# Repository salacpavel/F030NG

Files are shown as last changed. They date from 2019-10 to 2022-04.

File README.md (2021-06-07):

# F030NG
A ground-up remake of famous Atari Falcon 030 hardware, using contemporary components and technologies wherever possible, while maintaining maximum compatibility with original Atari system.
It aims to fix outstanding stability issues of original Falcon and introduces number of changes and exciting new features, such as
- **New (proprietary) thin desktop form factor**, closer to never released Atari Microbox030
- ~~Incorporates much, **much faster DSP with four times more on-board memory**~~ Due to identified incompatibilities of MC56303 DSP, on-board implementation of the DSP processor has been omitted in favour of expansion slot with all DSP signals on it. This enables development and use of DSP based plug-in boards in different configurations and forms, such as advanced digital sound cards, data processors, oscilloscopes, etc. Basic form of plug/in board will have MC56001 on it.
- Replaces fixed TOS/ROM socket with swappable add-on modules, what gives room for flash memory based TOS switchers etc.
- IDE port is relocated to allow simple use of cheap and ubiquitous CF-IDE adaptors, with CF conveniently accessible from the outside of the computer. Internal PATA laptop HDD is still an option
- External SCSI replaced with standard **internal 50 pin SCSI interface**. External port can be added with simple breakout board
- Removes two STE jagpad ports to save some space and simplify motherboard design
- ~~Expands internal expansion connector for additional pins to allow more different devices to be build, such as test and diagnostics cart (TBD), while still maintaining full compatibility with CT60(e) accelerator~~ no longer necessary, see below
- ~~Removes legacy cartridge interface due to general unavailability of replacement edge board connectors~~ Unobtainable legacy cartridge port edge card connector has been replaced with compatible replacement PCB/connector assebmbly
- **Redesigned TV-out circuit** is now based on more recent AD725 chip, providing higher quality output. S-Video output is now supported as well.
- Completely remade board power distribution to avoid need for most of leaky electrolytic capacitors. The rest of them is radial now, due to space and obsolescence concerns.
- **HiFi audio** components used for audio-in and audio-out
- Failing NVRAM chip replaced with more recent DS12885 backed by common replaceable CR1220 coin cell
- External and internal keyboard connectors
- Proprietary Atari 19-pin video connector replaced with common **VGA interface**. Now you can plug your VGA monitor directly, without a need for a convertor.
- Onboard implementation of NetUSB adds **one 10-mbit LAN port and two USB ports** (with number of USB devices currently supported)
- **Fully redesigned base clock system**. Whole universe of overclocking options is now available out of the box.  In example you can double the system clock while keeping CPU base clock, bump the CPU base clock in 8 steps, clock FPU independently, etc. Hard to obtain 32.098488MHz base clock crystal in no longer needed, unless you require 100% compatibility with clock-dependant graphics demos.
- Smaller motherboard footprint, with only 325.6x225mm outer dimensions
- Four-layer design compared to original six-layer Falcon mainboard for a lower production cost (around 20USD/pc) and easier manufacturing
- Optimized track routing to avoid infamous Falcon stability issue and need for different clock patches.
- Many more smaller fixes and changes, too many to name them all.

The F030 will eventually be available as bare/half-way/fully assembled mainboards and add-on cards through centuriontech.eu web shop, or available as a set of instruction, how-to and manufacturing data for DIY enthusiasts.

## Discussion platform:
Now you can discuss about F030NG on Discord: https://discord.gg/jRaXBVc

## Documentation:
Want to get started yourself? Read the [GitHub Wiki](https://github.com/salacpavel/F030NG/wiki)

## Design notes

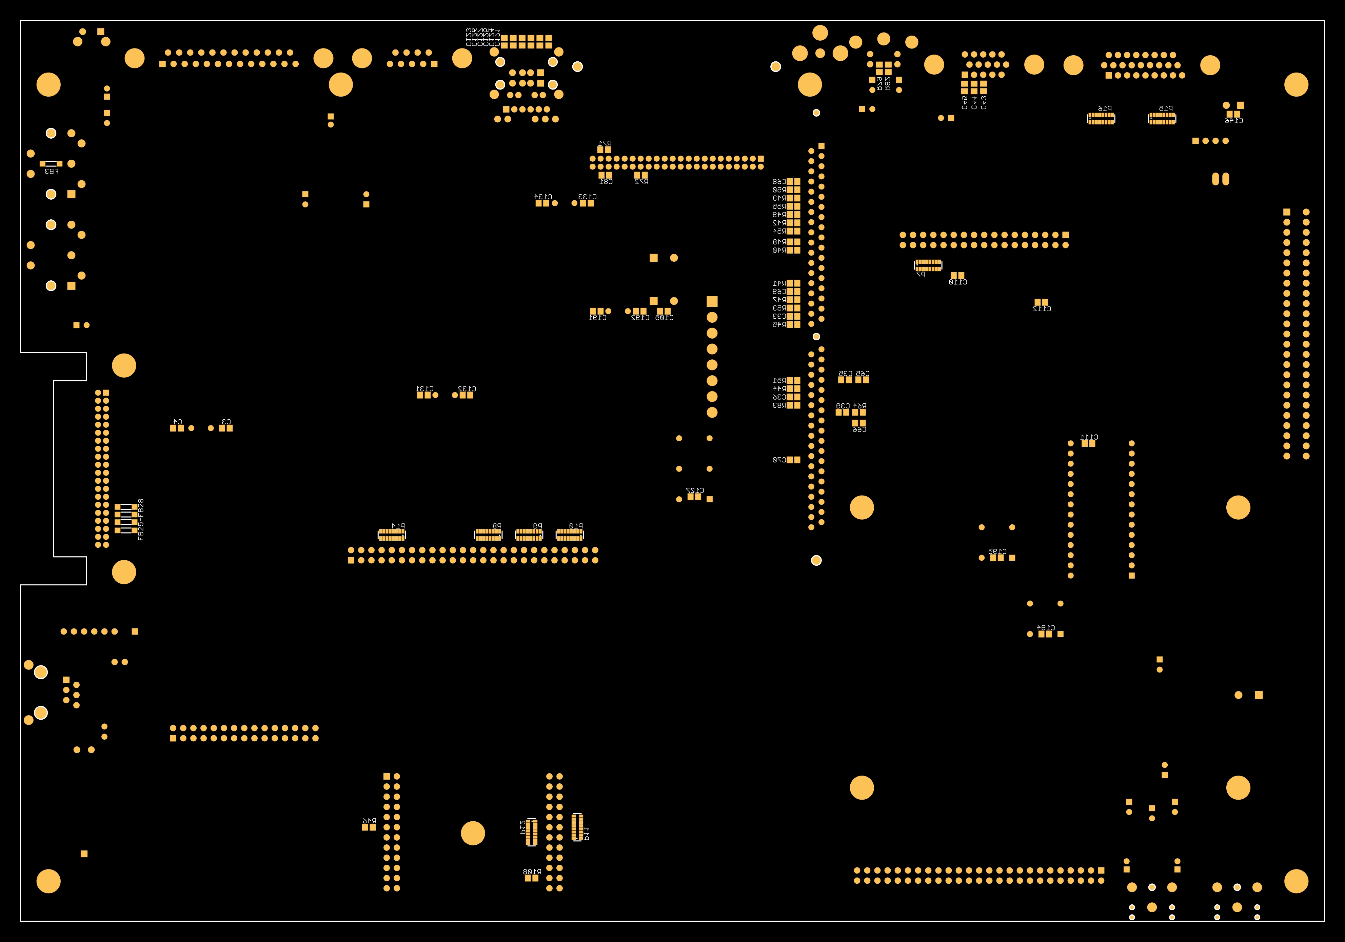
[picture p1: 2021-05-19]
F030NG_R02b bot.jpg

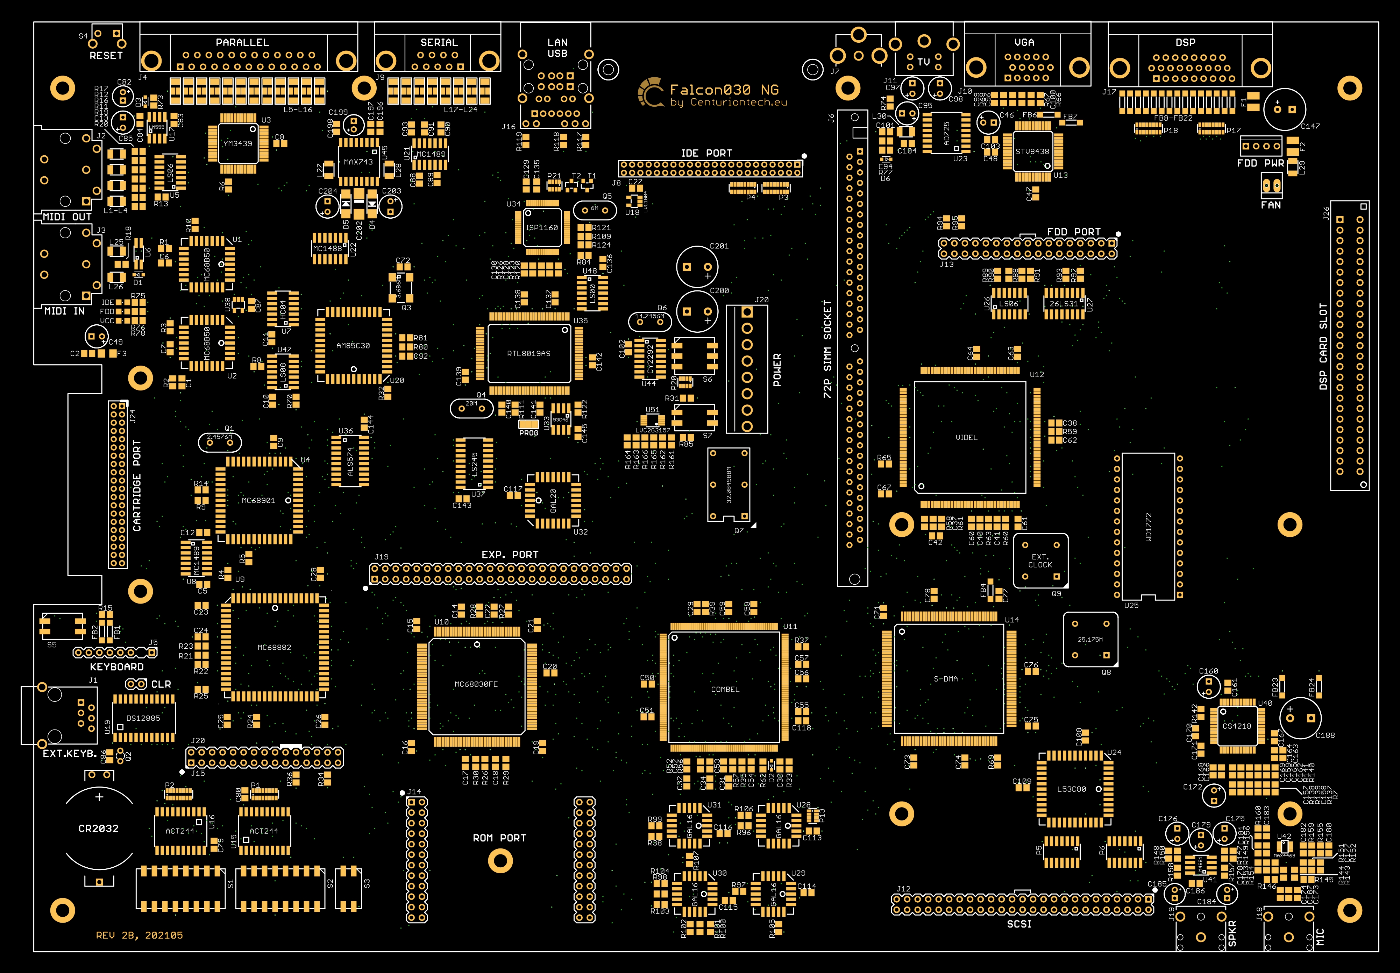
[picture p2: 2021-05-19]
F030NG_R02b top.JPG

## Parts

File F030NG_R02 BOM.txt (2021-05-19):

Part     Value                  Device                         Package          Library        Sheet

BAT1     CR2032                 CR2032-T                       CH29-2032        F030NG         8
C1       68p                    C-EUC0805                      C0805            rcl            1
C2       1u                     C-EUC0805                      C0805            rcl            15
C3       33p                    C-EUC0805                      C0805            rcl            1
C4       33p                    C-EUC0805                      C0805            rcl            1
C5       100p                   C-EUC0805                      C0805            rcl            1
C6       100n                   C-EUC0805                      C0805            rcl            1
C7       100n                   C-EUC0805                      C0805            rcl            1
C8       100n                   C-EUC0805                      C0805            rcl            1
C9       100n                   C-EUC0805                      C0805            rcl            1
C10      100n                   C-EUC0805                      C0805            rcl            1
C11      100n                   C-EUC0805                      C0805            rcl            1
C12      100n                   C-EUC0805                      C0805            rcl            1
C13      100n                   C-EUC0805                      C0805            rcl            1
C14      100n                   C-EUC0805                      C0805            rcl            2
C15      100n                   C-EUC0805                      C0805            rcl            2
C16      100n                   C-EUC0805                      C0805            rcl            2
C17      100n                   C-EUC0805                      C0805            rcl            2
C18      100n                   C-EUC0805                      C0805            rcl            2
C19      100n                   C-EUC0805                      C0805            rcl            2
C20      100n                   C-EUC0805                      C0805            rcl            2
C21      100n                   C-EUC0805                      C0805            rcl            2
C22      100n                   C-EUC0805                      C0805            rcl            2
C23      100n                   C-EUC0805                      C0805            rcl            2
C24      100n                   C-EUC0805                      C0805            rcl            2
C25      100n                   C-EUC0805                      C0805            rcl            2
C26      100n                   C-EUC0805                      C0805            rcl            2
C27      100n                   C-EUC0805                      C0805            rcl            8
C28      1u                     C-EUC0805                      C0805            rcl            2
C29      10p                    C-EUC0805                      C0805            rcl            3
C30      1u                     C-EUC0805                      C0805            rcl            3
C31      10p                    C-EUC0805                      C0805            rcl            3
C32      10p                    C-EUC0805                      C0805            rcl            3
C33      10p                    C-EUC0805                      C0805            rcl            3
C34      10p                    C-EUC0805                      C0805            rcl            3
C35      10p                    C-EUC0805                      C0805            rcl            3
C36      10p                    C-EUC0805                      C0805            rcl            3
C37      68p                    C-EUC0805                      C0805            rcl            3
C38      68p                    C-EUC0805                      C0805            rcl            3
C39      68p                    C-EUC0805                      C0805            rcl            3
C40      68p                    C-EUC0805                      C0805            rcl            3
C41      68p                    C-EUC0805                      C0805            rcl            3
C42      68p                    C-EUC0805                      C0805            rcl            3
C43      47p                    C-EUC0805                      C0805            rcl            3
C44      47p                    C-EUC0805                      C0805            rcl            3
C45      47p                    C-EUC0805                      C0805            rcl            3
C46      100u                   CPOL-EUE2.5-6                  E2,5-6           rcl            10
C47      100n                   C-EUC0805                      C0805            rcl            3
C48      100n                   C-EUC0805                      C0805            rcl            3
C49      100u                   CPOL-EUE2.5-6                  E2,5-6           rcl            15
C50      100n                   C-EUC0805                      C0805            rcl            3
C51      100n                   C-EUC0805                      C0805            rcl            3
C52      100n                   C-EUC0805                      C0805            rcl            3
C53      100n                   C-EUC0805                      C0805            rcl            3
C54      100n                   C-EUC0805                      C0805            rcl            3
C55      100n                   C-EUC0805                      C0805            rcl            3
C56      100n                   C-EUC0805                      C0805            rcl            3
C57      100n                   C-EUC0805                      C0805            rcl            3
C58      100n                   C-EUC0805                      C0805            rcl            3
C59      100n                   C-EUC0805                      C0805            rcl            3
C60      100n                   C-EUC0805                      C0805            rcl            3
C61      100n                   C-EUC0805                      C0805            rcl            3
C62      100n                   C-EUC0805                      C0805            rcl            3
C63      100n                   C-EUC0805                      C0805            rcl            3
C64      100n                   C-EUC0805                      C0805            rcl            3
C65      100n                   C-EUC0805                      C0805            rcl            3
C66      100n                   C-EUC0805                      C0805            rcl            3
C67      100n                   C-EUC0805                      C0805            rcl            3
C68      100n                   C-EUC0805                      C0805            rcl            4
C69      100n                   C-EUC0805                      C0805            rcl            4
C70      100n                   C-EUC0805                      C0805            rcl            4
C71      100n                   C-EUC0805                      C0805            rcl            5
C72      1u                     C-EUC0805                      C0805            rcl            22
C73      100n                   C-EUC0805                      C0805            rcl            5
C74      100n                   C-EUC0805                      C0805            rcl            5
C75      100n                   C-EUC0805                      C0805            rcl            5
C76      100n                   C-EUC0805                      C0805            rcl            5
C77      100n                   C-EUC0805                      C0805            rcl            5
C78      100n                   C-EUC0805                      C0805            rcl            5
C79      100n                   C-EUC0805                      C0805            rcl            6
C80      100n                   C-EUC0805                      C0805            rcl            6
C81      100n                   C-EUC0805                      C0805            rcl            7
C82      4u7                    CPOL-EUE2-5                    E2-5             rcl            8
C83      10n                    C-EUC0805                      C0805            rcl            8
C84      100n                   C-EUC0805                      C0805            rcl            8
C85      22u                    CPOL-EUE2.5-6                  E2,5-6           rcl            8
C86      100n                   C-EUC0805                      C0805            rcl            8
C87      100n                   C-EUC0805                      C0805            rcl            22
C88      100p                   C-EUC0805                      C0805            rcl            9
C89      100p                   C-EUC0805                      C0805            rcl            9
C90      100p                   C-EUC0805                      C0805            rcl            9
C91      100p                   C-EUC0805                      C0805            rcl            9
C92      100n                   C-EUC0805                      C0805            rcl            9
C93      100n                   C-EUC0805                      C0805            rcl            9
C94      10p                    C-EUC0805                      C0805            rcl            10
C95      220u                   CPOL-EUE2.5-6                  E2,5-6           rcl            10
C96      100n                   C-EUC0805                      C0805            rcl            10
C97      220u                   CPOL-EUE2.5-6                  E2,5-6           rcl            10
C98      220u                   CPOL-EUE2.5-6                  E2,5-6           rcl            10
C99      100n                   C-EUC0805                      C0805            rcl            10
C100     100n                   C-EUC0805                      C0805            rcl            10
C101     22p                    C-EUC0805                      C0805            rcl            10
C102     100n                   C-EUC0805                      C0805            rcl            22
C103     100n                   C-EUC0805                      C0805            rcl            10
C104     100n                   C-EUC0805                      C0805            rcl            10
C105     100n                   C-EUC0805                      C0805            rcl            23
C107     100n                   C-EUC0805                      C0805            rcl            22
C108     22n                    C-EUC0805                      C0805            rcl            11
C109     100n                   C-EUC0805                      C0805            rcl            11
C110     100n                   C-EUC0805                      C0805            rcl            12
C111     100n                   C-EUC0805                      C0805            rcl            12
C112     100n                   C-EUC0805                      C0805            rcl            12
C113     100n                   C-EUC0805                      C0805            rcl            13
C114     100n                   C-EUC0805                      C0805            rcl            13
C115     100n                   C-EUC0805                      C0805            rcl            13
C116     100n                   C-EUC0805                      C0805            rcl            13
C117     100n                   C-EUC0805                      C0805            rcl            13
C118     100n                   C-EUC0805                      C0805            rcl            16
C121     1u                     C-EUC0805                      C0805            rcl            17
C123     47p                    C-EUC0805                      C0805            rcl            17
C124     1u                     C-EUC0805                      C0805            rcl            17
C125     47p                    C-EUC0805                      C0805            rcl            17
C126     47p                    C-EUC0805                      C0805            rcl            17
C127     47p                    C-EUC0805                      C0805            rcl            17
C128     100n                   C-EUC0805                      C0805            rcl            17
C129     100n                   C-EUC0805                      C0805            rcl            17
C130     100n                   C-EUC0805                      C0805            rcl            17
C131     22p                    C-EUC0805                      C0805            rcl            17
C132     22p                    C-EUC0805                      C0805            rcl            17
C133     22p                    C-EUC0805                      C0805            rcl            17
C134     22p                    C-EUC0805                      C0805            rcl            17
C135     100n                   C-EUC0805                      C0805            rcl            17
C136     100n                   C-EUC0805                      C0805            rcl            17
C137     100n                   C-EUC0805                      C0805            rcl            17
C138     100n                   C-EUC0805                      C0805            rcl            17
C139     100n                   C-EUC0805                      C0805            rcl            17
C140     100n                   C-EUC0805                      C0805            rcl            17
C141     100n                   C-EUC0805                      C0805            rcl            17
C142     100n                   C-EUC0805                      C0805            rcl            17
C143     100n                   C-EUC0805                      C0805            rcl            17
C144     100n                   C-EUC0805                      C0805            rcl            17
C145     100n                   C-EUC0805                      C0805            rcl            17
C146     100n                   C-EUC0805                      C0805            rcl            23
C147     220u lESR              CPOL-EUE3.5-10                 E3,5-10          rcl            23
C157     10n                    C-EUC0805                      C0805            rcl            20
C158     10n                    C-EUC0805                      C0805            rcl            20
C159     470n                   C-EUC0805                      C0805            rcl            20
C160     10u                    CPOL-EUE2.5-6                  E2,5-6           rcl            20
C161     100n                   C-EUC0805                      C0805            rcl            20
C162     470n                   C-EUC0805                      C0805            rcl            20
C163     10n                    C-EUC0805                      C0805            rcl            20
C164     470n                   C-EUC0805                      C0805            rcl            20
C165     470n                   C-EUC0805                      C0805            rcl            20
C166     680p                   C-EUC0805                      C0805            rcl            20
C167     100n                   C-EUC0805                      C0805            rcl            20
C168     680p                   C-EUC0805                      C0805            rcl            20
C169     100n                   C-EUC0805                      C0805            rcl            20
C170     2n2                    C-EUC0805                      C0805            rcl            20
C171     2n2                    C-EUC0805                      C0805            rcl            20
C172     10u                    CPOL-EUE2.5-6                  E2,5-6           rcl            20
C173     100n                   C-EUC0805                      C0805            rcl            21
C174     100n                   C-EUC0805                      C0805            rcl            21
C175     0.33u                  CPOL-EUE2.5-6                  E2,5-6           rcl            21
C176     0.33u                  CPOL-EUE2.5-6                  E2,5-6           rcl            21
C177     10n                    C-EUC0805                      C0805            rcl            21
C178     10n                    C-EUC0805                      C0805            rcl            21
C179     1u                     CPOL-EUE2.5-6                  E2,5-6           rcl            21
C180     1u                     C-EUC0805                      C0805            rcl            21
C181     1u                     C-EUC0805                      C0805            rcl            21
C182     100p                   C-EUC0805                      C0805            rcl            21
C183     100p                   C-EUC0805                      C0805            rcl            21
C184     1u                     CPOL-AUDIOE2/5                 E2-5             rcl            21
C185     1u                     CPOL-AUDIOE2/5                 E2-5             rcl            21
C186     100n                   C-EUC0805                      C0805            rcl            21
C187     100n                   C-EUC0805                      C0805            rcl            21
C188     47u                    CPOL-EUE5-10.5                 E5-10,5          rcl            21
C191     20p                    C-EUC0805                      C0805            rcl            22
C192     20p                    C-EUC0805                      C0805            rcl            22
C194     100n                   C-EUC0805                      C0805            rcl            22
C195     1u                     C-EUC0805                      C0805            rcl            22
C196     10n                    C-EUC0805                      C0805            rcl            23
C197     100n                   C-EUC0805                      C0805            rcl            23
C198     10n                    C-EUC0805                      C0805            rcl            23
C199     10u                    CPOL-EUE2-5                    E2-5             rcl            23
C200     1000u lESR             CPOL-EUE5-10.5                 E5-10,5          rcl            23
C201     1000u lESR             CPOL-EUE5-10.5                 E5-10,5          rcl            23
C202     22uF                   CPOL-EUSMCC                    SMC_C            rcl            23
C203     100u lowESR            CPOL-EUE2.5-6                  E2,5-6           rcl            23
C204     100u lowESR            CPOL-EUE2.5-6                  E2,5-6           rcl            23
D1       1N914                  DIODE-SOD323-R                 SOD323-R         diode          1
D2       1N914                  DIODE-SOD323-R                 SOD323-R         diode          3
D3       1N914                  DIODE-SOD323-R                 SOD323-R         diode          8
D4       SM5817                 SM5817-DO                      DO213AB          F030NG         23
D5       SM5817                 SM5817-DO                      DO213AB          F030NG         23
D6       1N914                  DIODE-SOD323-R                 SOD323-R         diode          10
F1       15V/0.5A               F-1210                         1210             F030NG         18
F2       6V/0.5A                F-1210                         1210             F030NG         23
F3       6V/0.5A                F-1206                         1206             F030NG         15
FB1                             FB_1806(WB/HS)                 WE-1806(W=5.5)   F030NG         1
FB2                             FB_1806(WB/HS)                 WE-1806(W=5.5)   F030NG         1
FB3                             FB_1806(WB/HS)                 WE-1806(W=5.5)   F030NG         1
FB4                             FB_1806(WB/HS)                 WE-1806(W=5.5)   F030NG         5
FB6                             FB_1806(WB/HS)                 WE-1806(W=5.5)   F030NG         10
FB7                             FB_1806(WB/HS)                 WE-1806(W=5.5)   F030NG         10
FB8                             FB_1806(WB/HS)                 WE-1806(W=5.5)   F030NG         18
FB9                             FB_1806(WB/HS)                 WE-1806(W=5.5)   F030NG         18
FB10                            FB_1806(WB/HS)                 WE-1806(W=5.5)   F030NG         18
FB11                            FB_1806(WB/HS)                 WE-1806(W=5.5)   F030NG         18
FB12                            FB_1806(WB/HS)                 WE-1806(W=5.5)   F030NG         18
FB13                            FB_1806(WB/HS)                 WE-1806(W=5.5)   F030NG         18
FB14                            FB_1806(WB/HS)                 WE-1806(W=5.5)   F030NG         18
FB15                            FB_1806(WB/HS)                 WE-1806(W=5.5)   F030NG         18
FB16                            FB_1806(WB/HS)                 WE-1806(W=5.5)   F030NG         18
FB17                            FB_1806(WB/HS)                 WE-1806(W=5.5)   F030NG         18
FB18                            FB_1806(WB/HS)                 WE-1806(W=5.5)   F030NG         18
FB19                            FB_1806(WB/HS)                 WE-1806(W=5.5)   F030NG         18
FB20                            FB_1806(WB/HS)                 WE-1806(W=5.5)   F030NG         18
FB21                            FB_1806(WB/HS)                 WE-1806(W=5.5)   F030NG         18
FB22                            FB_1806(WB/HS)                 WE-1806(W=5.5)   F030NG         18
FB23                            FB_1806(WB/HS)                 WE-1806(W=5.5)   F030NG         20
FB24                            FB_1806(WB/HS)                 WE-1806(W=5.5)   F030NG         20
FB25                            FB_1806(WB/HS)                 WE-1806(W=5.5)   F030NG         15
FB26                            FB_1806(WB/HS)                 WE-1806(W=5.5)   F030NG         15
FB27                            FB_1806(WB/HS)                 WE-1806(W=5.5)   F030NG         15
FB28                            FB_1806(WB/HS)                 WE-1806(W=5.5)   F030NG         15
GND                             MOUNT_FDD                      MOUNTPADS_FDD    F030NG         25
H1       MOUNT-PAD-ROUND3.2D3.2 MOUNT-PAD-ROUND3.2D3.2         3,2-PAD          F030NG         25
H2       MOUNT-PAD-ROUND3.2D3.2 MOUNT-PAD-ROUND3.2D3.2         3,2-PAD          F030NG         25
H3       MOUNT-PAD-ROUND3.2D3.2 MOUNT-PAD-ROUND3.2D3.2         3,2-PAD          F030NG         25
H4       MOUNT-PAD-ROUND3.2D3.2 MOUNT-PAD-ROUND3.2D3.2         3,2-PAD          F030NG         25
H5       MOUNT-PAD-ROUND3.2D3.2 MOUNT-PAD-ROUND3.2D3.2         3,2-PAD          F030NG         25
H6       MOUNT-PAD-ROUND3.2D3.2 MOUNT-PAD-ROUND3.2D3.2         3,2-PAD          F030NG         25
H7       MOUNT-PAD-ROUND3.2D3.2 MOUNT-PAD-ROUND3.2D3.2         3,2-PAD          F030NG         25
J1                              RJ-12_CONN                     TE_RJ12GE-AMP    F030NG         1
J2       MIDI OUT               MIDI                           MAB5SH           F030NG         1
J3       MIDI IN                MIDI                           MAB5SH           F030NG         1
J4       PARALLEL-DB25F         PARALLEL-DB25F                 DB25F            F030NG         1
J5                              KEYBOARD                       PH_KEYBOARD      F030NG         1
J6                              SIMM72-VERT                    TE_5822021-4     F030NG         4
J7       RCA_SOCKET             RCA_SOCKET                     KEYS938          F030NG         10
J8       IDE_CONN-CF            IDE_CONN-CF                    CF_IDE           F030NG         7
J9       SERIAL-DB9             SERIAL-DB9                     DB9M             F030NG         9
J10      VGA-REG                VGA-REG                        DB15F            F030NG         10
J11      MINI_DIN4P             MINI_DIN4P                     MINI_DIN4P       F030NG         10
J12      SCSI                   SCSI_CONN_INTCOM               PH_2X25_COMBI    F030NG         11
J13      FDD_CONNCOM            FDD_CONNCOM                    PH_2X17_COMBI    F030NG         12
J14                             ROM_INTERFACE                  PH_ROM_PORT      F030NG         14
J15                             CPU_EXP_PORT                   PH_CPU_EXP_PORT  F030NG         16
J16      0862-1JX1-43-F         RJ45_DUAL-USB                  JY0-0016         F030NG         17
J17      DSP_PORT-DB26F         DSP_PORT-DB26F                 DB26F            F030NG         18
J18      MIC                    3.5MM_SOCKET3P                 JY039-3P         F030NG         21
J19      SPKR                   3.5MM_SOCKET3P                 JY039-3P         F030NG         21
J20      POWER_CONN-8P          POWER_CONN-8P                  MOLEX_09-65-2088 F030NG         23
J21      TE_171825-4            FDD_CONN_PWR                   TE_171825-4      F030NG         23
J22                             JUMPER-2P                      PH_1X02          F030NG         8
J23      FAN_PWR                22-23-2021                     22-23-2021       con-molex      23
J24                             40PCART_NEWMEC2-20-01-L-DV-NP  40PCART_SAMTEC   F030NG         15
J26      5530843-5              5530843-5                      55308435         SamacSys_Parts 19
L1       1uH                    L-1210                         L1210            F030NG         1
L2       1uH                    L-1210                         L1210            F030NG         1
L3       1uH                    L-1210                         L1210            F030NG         1
L4       1uH                    L-1210                         L1210            F030NG         1
L5       NFM41CC222R2A3L        LCL1806                        NFM41C           F030NG         1
L6       NFM41CC222R2A3L        LCL1806                        NFM41C           F030NG         1
L7       NFM41CC222R2A3L        LCL1806                        NFM41C           F030NG         1
L8       NFM41CC222R2A3L        LCL1806                        NFM41C           F030NG         1
L9       NFM41CC222R2A3L        LCL1806                        NFM41C           F030NG         1
L10      NFM41CC222R2A3L        LCL1806                        NFM41C           F030NG         1
L11      NFM41CC222R2A3L        LCL1806                        NFM41C           F030NG         1
L12      NFM41CC222R2A3L        LCL1806                        NFM41C           F030NG         1
L13      NFM41CC222R2A3L        LCL1806                        NFM41C           F030NG         1
L14      NFM41CC222R2A3L        LCL1806                        NFM41C           F030NG         1
L15      NFM41CC222R2A3L        LCL1806                        NFM41C           F030NG         1
L16      NFM41CC222R2A3L        LCL1806                        NFM41C           F030NG         1
L17      NFM41CC222R2A3L        LCL1806                        NFM41C           F030NG         9
L18      NFM41CC222R2A3L        LCL1806                        NFM41C           F030NG         9
L19      NFM41CC222R2A3L        LCL1806                        NFM41C           F030NG         9
L20      NFM41CC222R2A3L        LCL1806                        NFM41C           F030NG         9
L21      NFM41CC222R2A3L        LCL1806                        NFM41C           F030NG         9
L22      NFM41CC222R2A3L        LCL1806                        NFM41C           F030NG         9
L23      NFM41CC222R2A3L        LCL1806                        NFM41C           F030NG         9
L24      NFM41CC222R2A3L        LCL1806                        NFM41C           F030NG         9
L25      1uH                    L-1210                         L1210            F030NG         1
L26      1uH                    L-1210                         L1210            F030NG         1
L27      100uH                  L-1210                         L1210            F030NG         23
L28      100uH                  L-1210                         L1210            F030NG         23
L29      4u7                    L-1210                         L1210            F030NG         23
L30      68uH                   L-1210                         L1210            F030NG         10
LED1     LTST-C171KSKT          LEDCHIPLED_0805                CHIPLED_0805     led            8
LED2     LTST-C171KSKT          LEDCHIPLED_0805                CHIPLED_0805     led            8
LED4     LTST-C171KGKT          LEDCHIPLED_0805                CHIPLED_0805     led            8
P1       8x10k                  R-ARRAY_8R742-16NS             CTS-742-16NS     F030NG         6
P2       8x10k                  R-ARRAY_8R742-16NS             CTS-742-16NS     F030NG         6
P3       8x4k7                  R-ARRAY_8R742-16NS             CTS-742-16NS     F030NG         7
P4       8x4k7                  R-ARRAY_8R742-16NS             CTS-742-16NS     F030NG         7
P5       220/330                CTS766                         SO14             F030NG         11
P6       220/330                CTS766                         SO14             F030NG         11
P7       8x1k                   R-ARRAY_8R742-16NS             CTS-742-16NS     F030NG         12
P8       8x4k7                  R-ARRAY_8R742-16NS             CTS-742-16NS     F030NG         14
P9       8x4k7                  R-ARRAY_8R742-16NS             CTS-742-16NS     F030NG         14
P10      8x4k7                  R-ARRAY_8R742-16NS             CTS-742-16NS     F030NG         14
P11      8x10k                  R-ARRAY_8R742-16NS             CTS-742-16NS     F030NG         14
P12      8x10k                  R-ARRAY_8R742-16NS             CTS-742-16NS     F030NG         14
P13      4x10k                  R-ARRAY_4RCTS-774-8NS          CTS-774-8NS      F030NG         16
P14      8x1k2                  R-ARRAY_8R742-16NS             CTS-742-16NS     F030NG         16
P15      8x47k                  R-ARRAY_8R742-16NS             CTS-742-16NS     F030NG         18
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

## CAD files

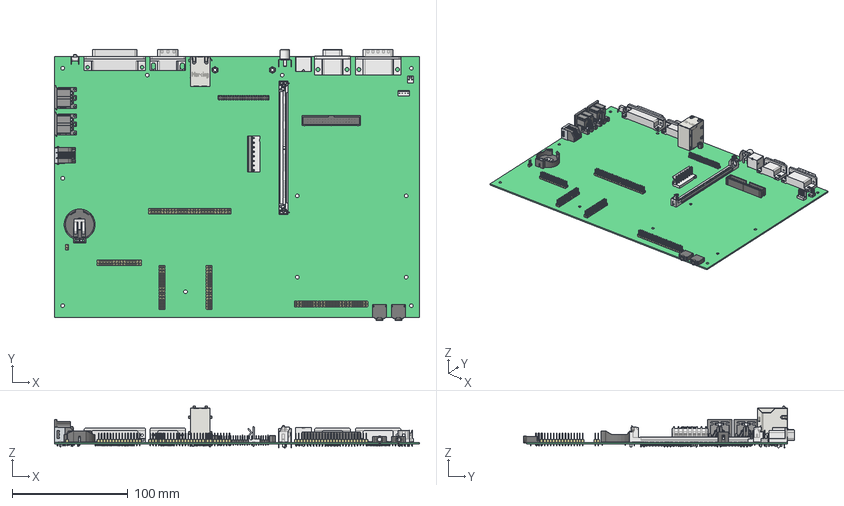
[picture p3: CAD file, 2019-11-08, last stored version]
3D models/mainboard/F030NG_rev.A_20191106.FCStd
315.1 x 234.4 x 36.1 mm
Mainboard
Insulator
Shielding
Insulator001
Shielding_3
Pin_1
Pin_002
Pin_003
Pin_004
Pin_2
Pin_005
Pin_006
Pin_007
Shielding001
VGA conn
DSP conn
StandoffL
StandoffL001
Serial conn
Parallel conn
Reset switch
housing
spring
pin
Shielding002
housing001
pin6'
pin5'
pin3'
pin4'
pin2'
pin1'
Svideo conn
FDD_pwr conn
SIMM conn
MIC conn
SPKR conn
Composite TV out conn
FDD conn
Stiftleiste_Male001
Stiftleiste_Male002
Stiftleiste_Male003
Stiftleiste_Male004
Stiftleiste_Male005
Stiftleiste_Male006
Stiftleiste_Male007
Stiftleiste_Male008
Stiftleiste_Male009
Stiftleiste_Male010
Stiftleiste_Male011
Stiftleiste_Male012
Stiftleiste_Male013
Stiftleiste_Male014
Stiftleiste_Male015
Stiftleiste_Male016
Stiftleiste_Male017
Stiftleiste_Male018
Stiftleiste_Male019
Stiftleiste_Male020
Stiftleiste_Male021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

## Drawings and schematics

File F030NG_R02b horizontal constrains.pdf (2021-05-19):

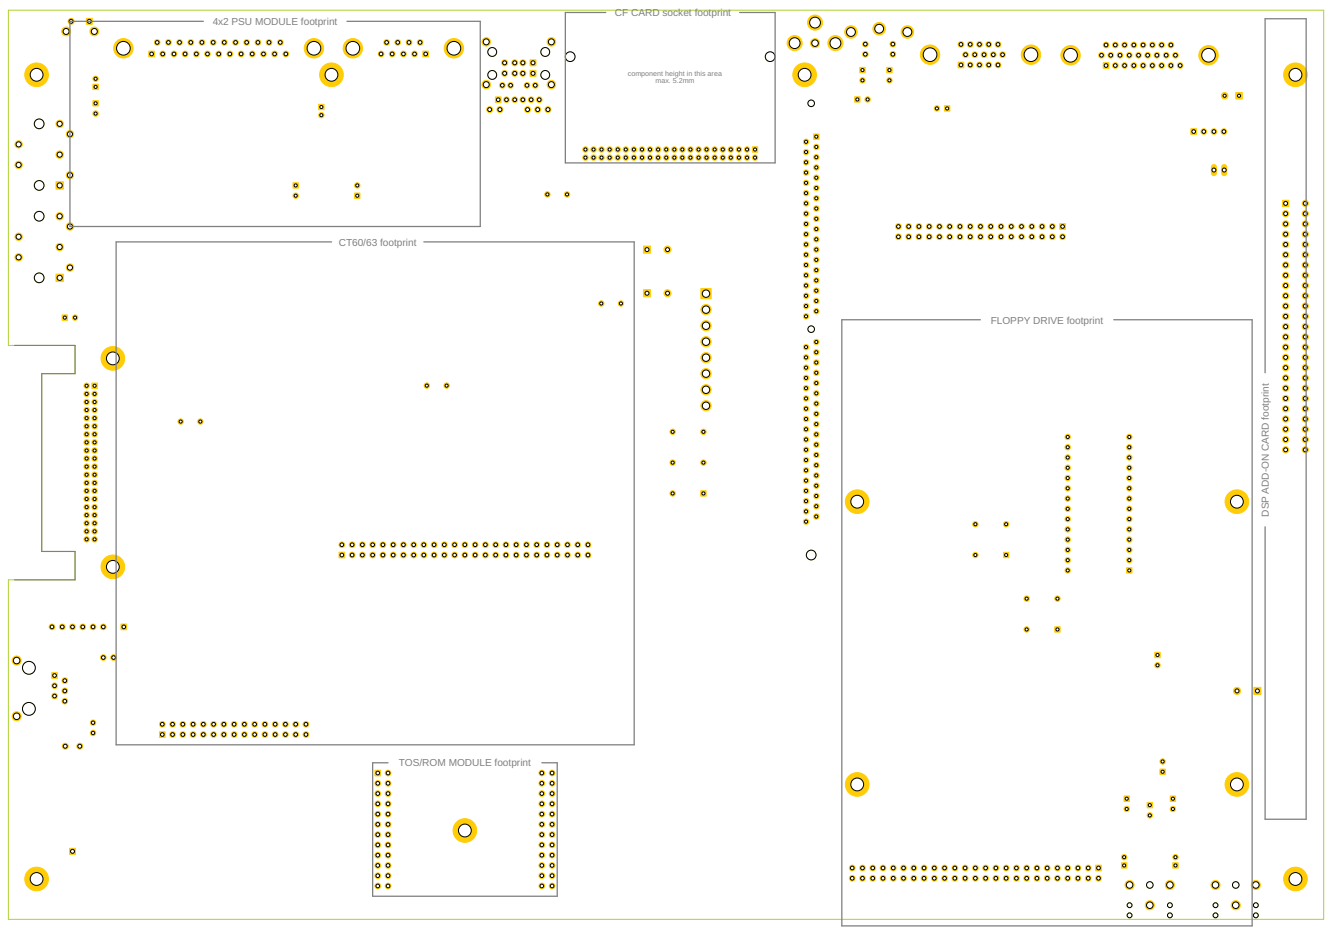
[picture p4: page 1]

CF CARD socket footprint

component height in this area max. 5.2mm

DSP ADD-ON CARD footprint

TOS/ROM MODULE footprint

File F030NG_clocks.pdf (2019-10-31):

LAN | MFP

### USB

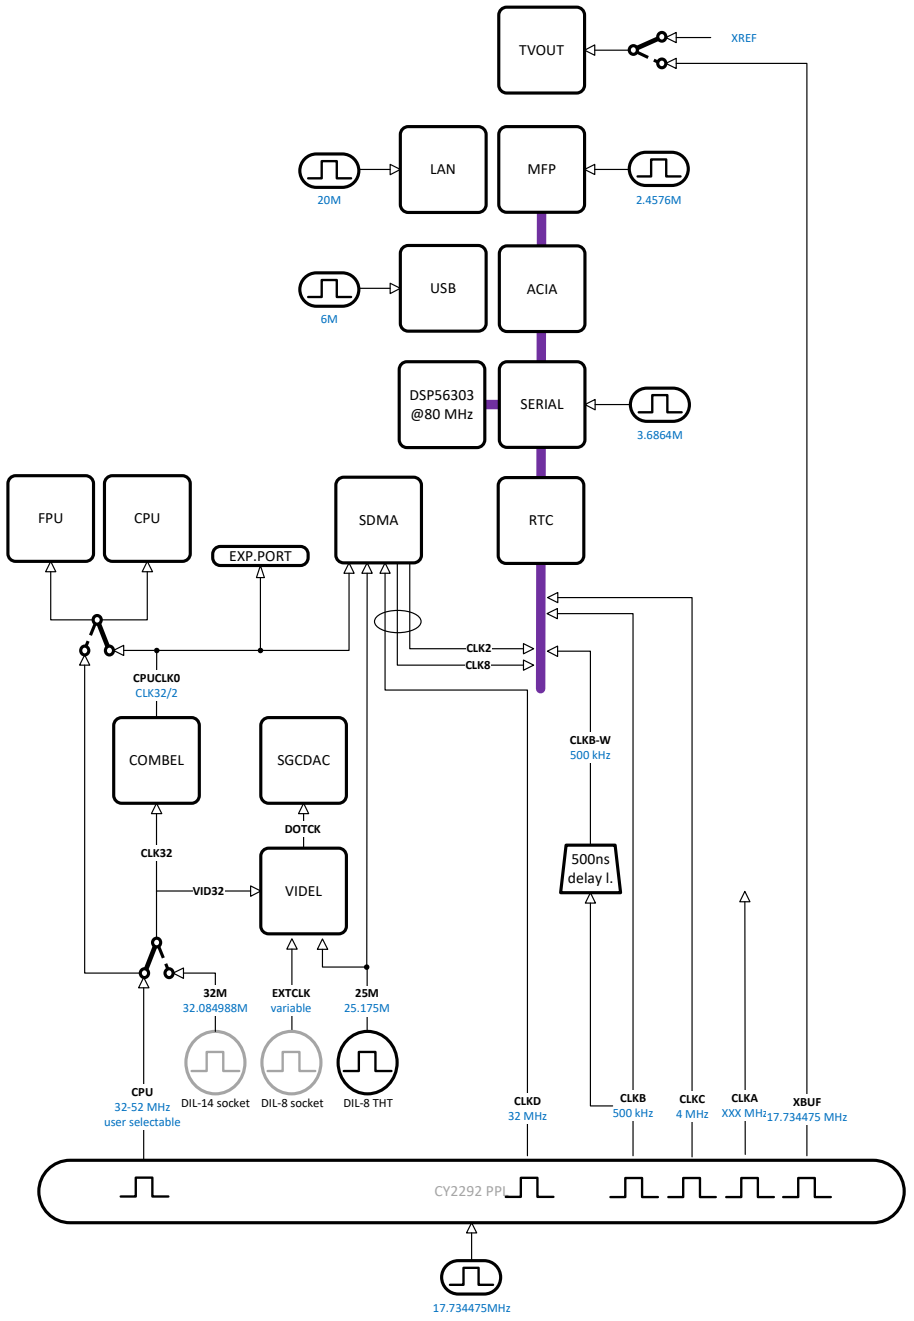
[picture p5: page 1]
COMBEL; FPU; CPU; SDMA; EXP.PORT; CPUCLK0 CLK32/2; VIDEL; RTC; SGCDAC; DOTCK; CLK32; ACIA; SERIAL; CLK8; CLK2; CY2292 PPL; CLKD 32 MHz; CPU 32-52 MHz user selectable; CLKA XXX MHz; CLKC 4 MHz; DSP56303 @80 MHz; CLKB 500 kHz; 500ns delay l.; CLKB-W 500 kHz; EXTCLK variable; VID32; DIL-14 socket DIL-8 socket; DIL-8 THT; XBUF 17.734475 MHz; 17.734475MHz; TVOUT; XREF

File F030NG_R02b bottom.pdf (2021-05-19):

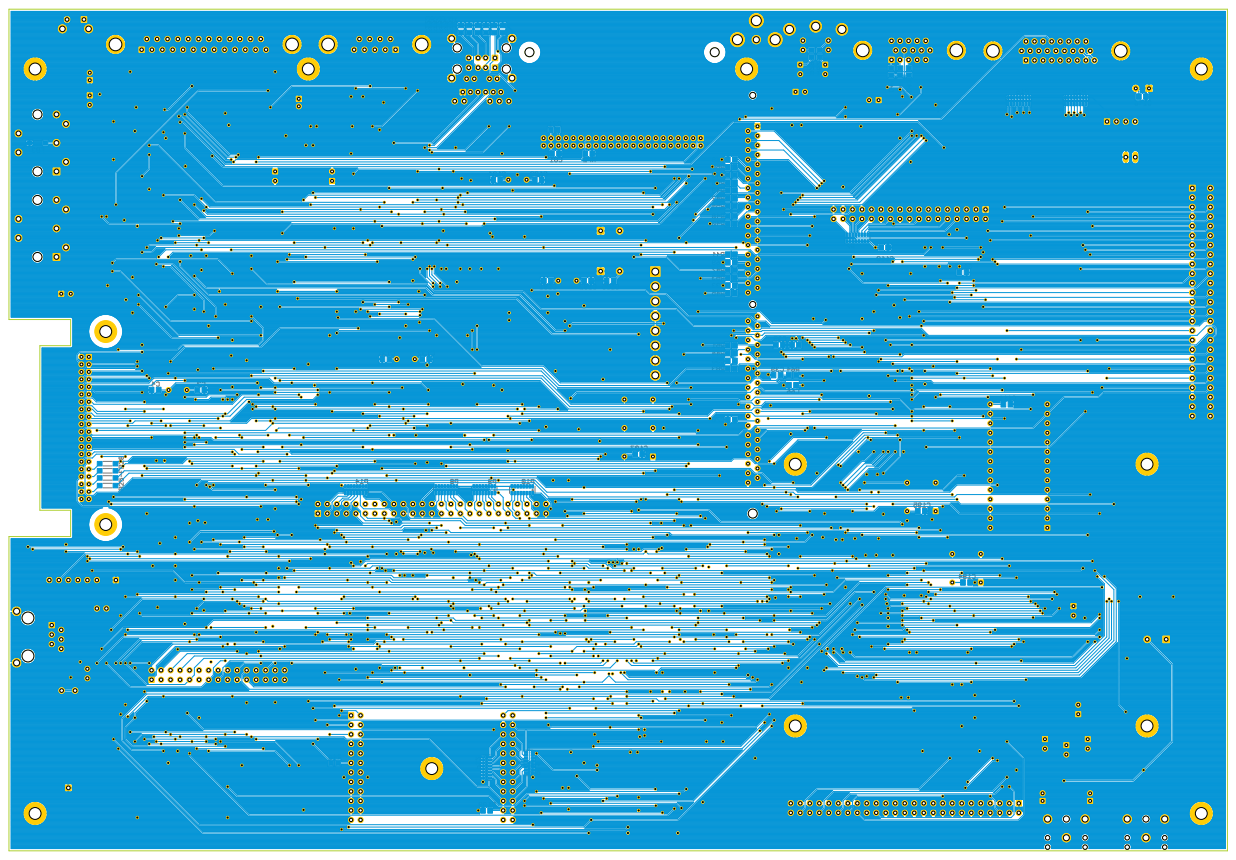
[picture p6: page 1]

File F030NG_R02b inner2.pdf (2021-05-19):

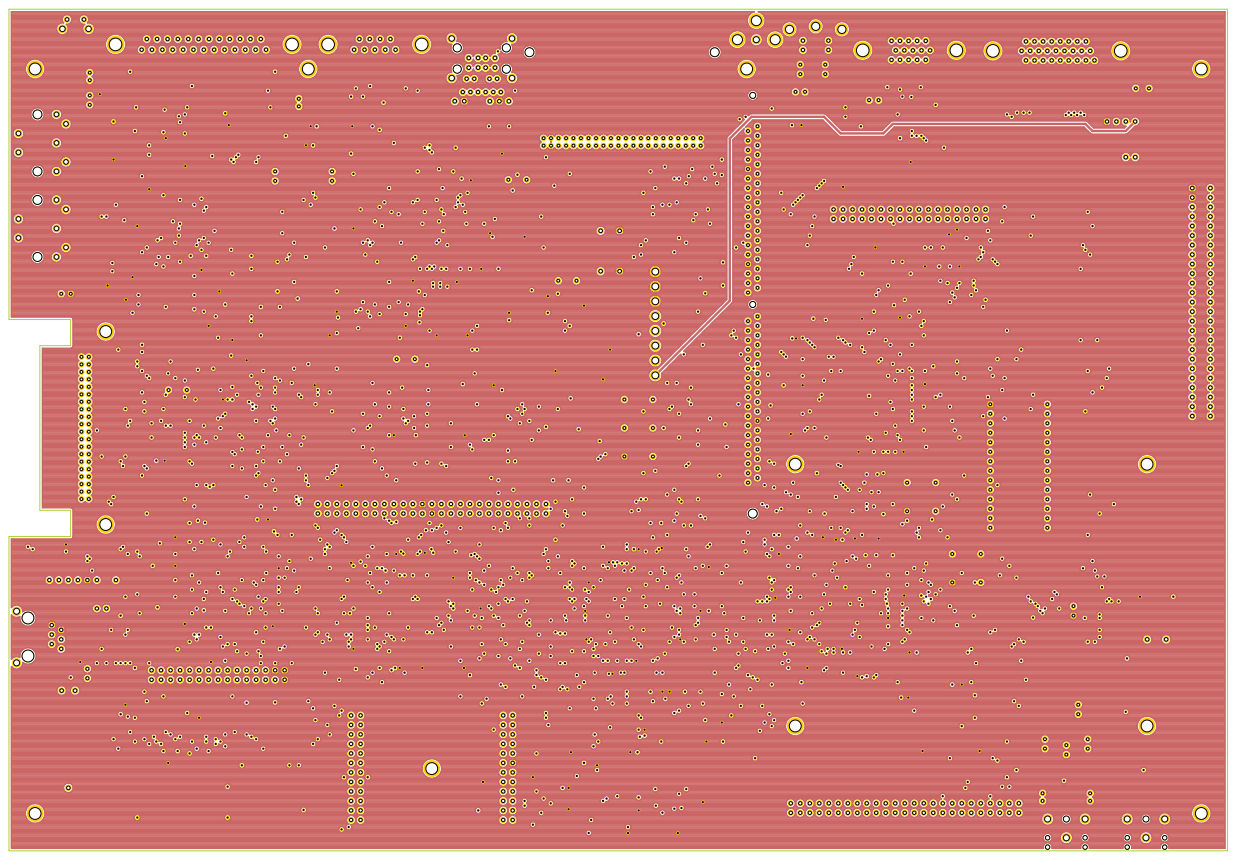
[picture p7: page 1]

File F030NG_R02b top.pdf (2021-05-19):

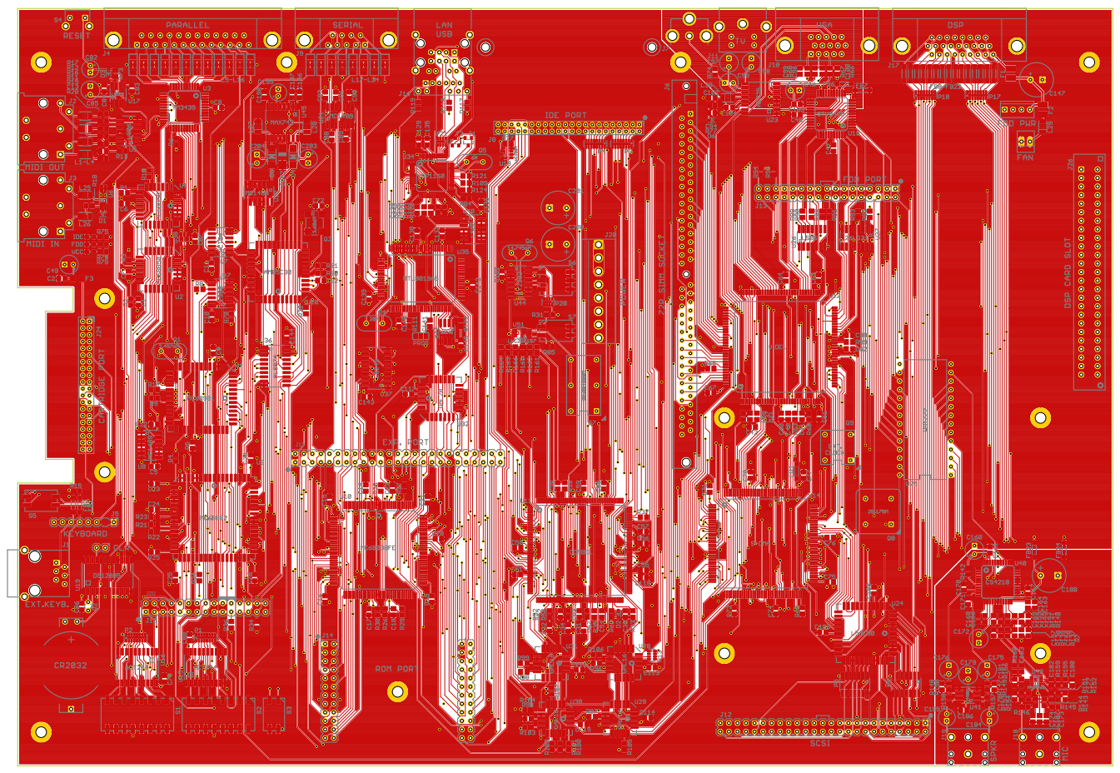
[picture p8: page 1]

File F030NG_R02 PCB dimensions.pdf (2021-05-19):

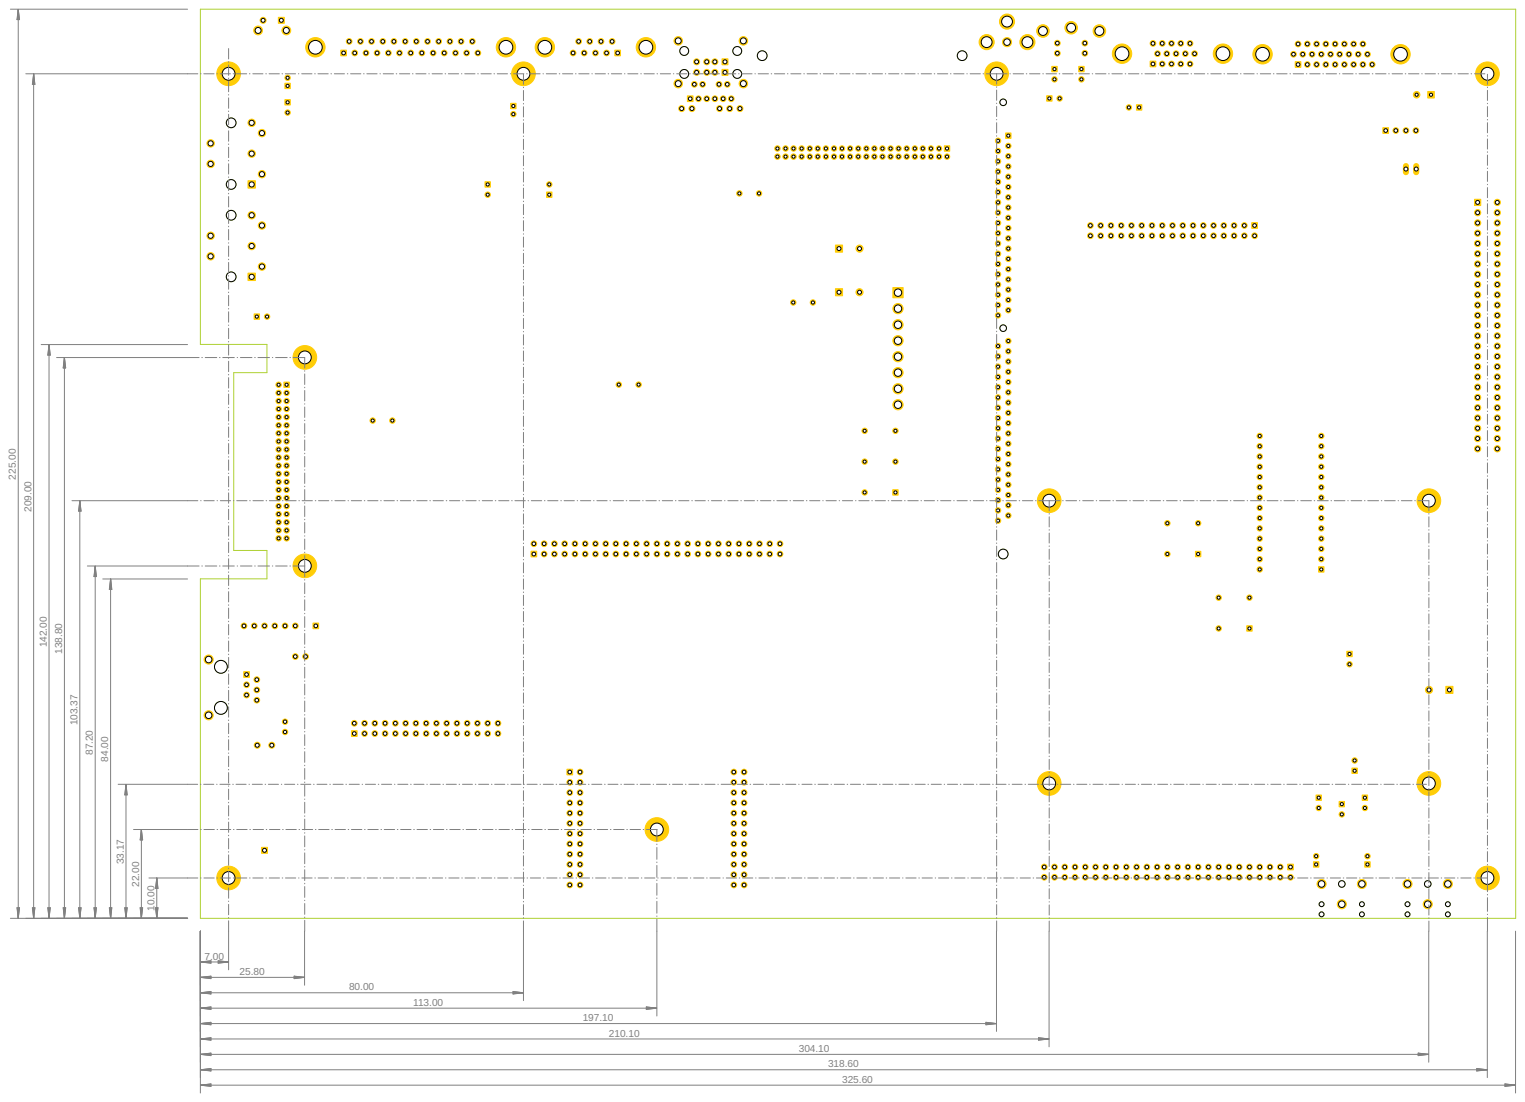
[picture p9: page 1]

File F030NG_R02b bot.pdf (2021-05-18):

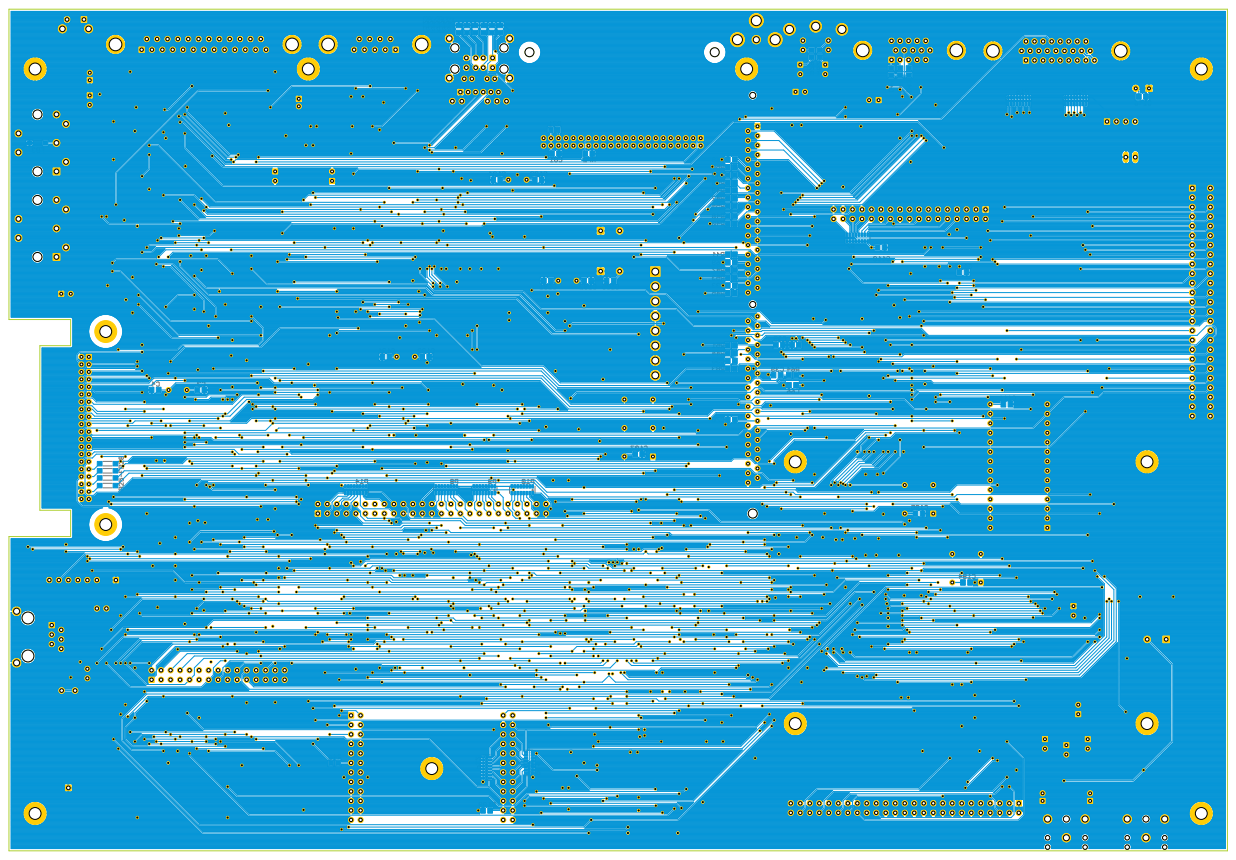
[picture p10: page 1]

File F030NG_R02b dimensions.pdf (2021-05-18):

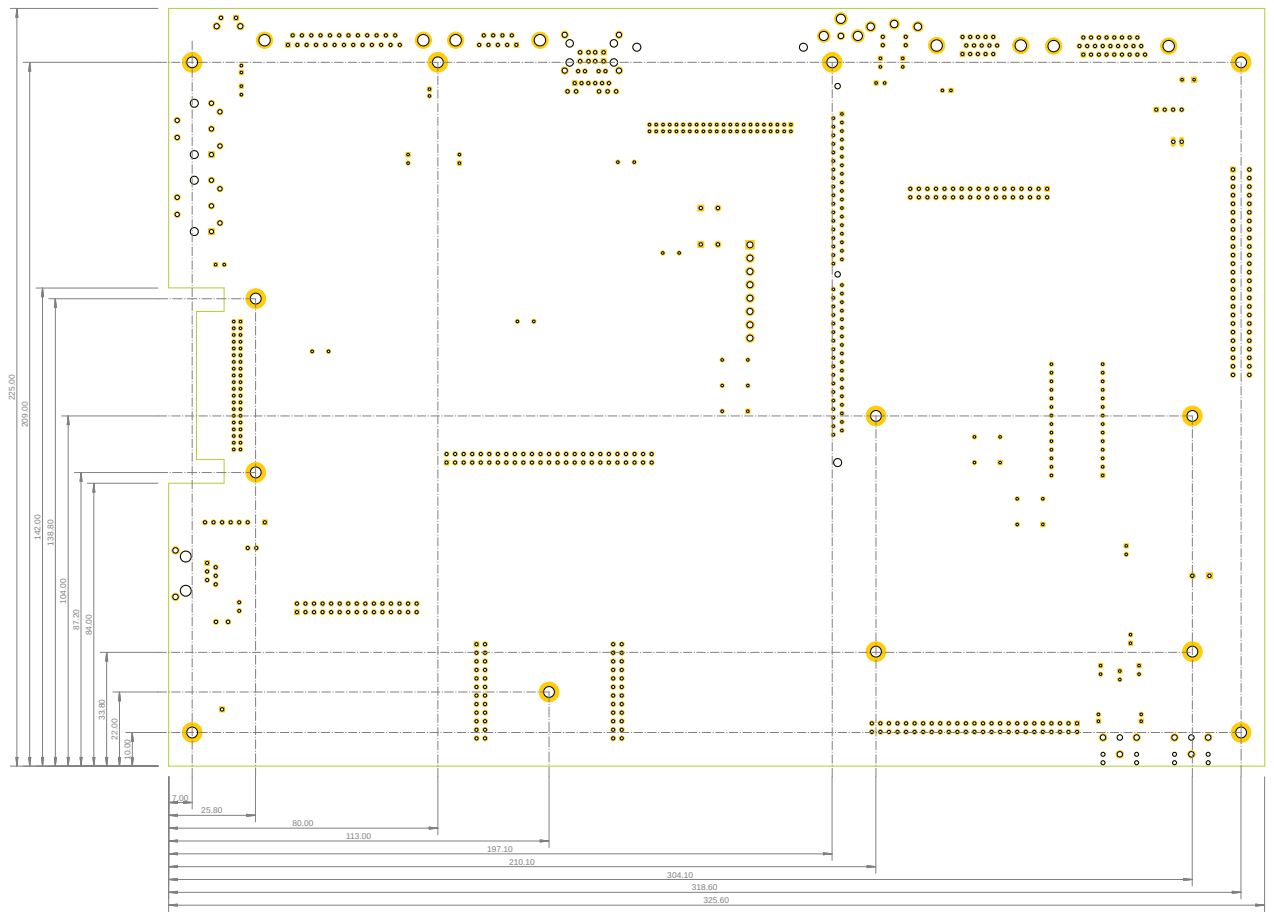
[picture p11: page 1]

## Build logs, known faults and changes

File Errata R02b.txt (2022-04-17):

Q3:silkscreen value to be corrected to 3.672MHz. Possible technology change to 5V/DIL14 packaging (can be programmed from blanks)
Q6:silkscreen value to be corrected to 17.734476MHz (PAL version)
Q1:technology change from HC-49/S to HC-49/U, as short version is simply unavailable. Affects silkscreen only.
P1-4,7-12,14-18: for future revisions, split to 4xresistor packs
Q2: possibly change to SMT technology

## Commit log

2019-10-31 LAN connector cleanups
2019-10-31 R108 silkscreen fix
2019-10-31 Connector descriptions added, silkscreen fixes
2019-11-01 LAN acct. LEDs swap
2019-11-01 C1 moved next to R2 to form proper LC filter, silkscreen cleanups
2019-11-05 Added IC IDs to silkscreen for easier assembly
2019-11-05 Yet more silkscreen fixes
2019-11-08 Added more detailed components, .STEP export
    [F030NG_rev.A_20191106.FCStd]
2019-12-31 Update README.md
    preliminary updates for rev.B board
2020-01-23 SSOP14/16 TI landing pattern fixes
2020-02-19 ISP1160 TEST_L pin fix
2021-05-19 Add files via upload
    2MM DSP CARD SLOT added
